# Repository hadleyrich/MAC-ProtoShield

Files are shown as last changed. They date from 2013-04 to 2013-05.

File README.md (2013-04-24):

MAC ProtoShield
===============
Copyright 2013 nice technology Ltd  
Website: <http://nicegear.co/mac-protoshield>

Based on the Freetronics ProtoShieldShort
<http://www.freetronics.com/pss>

A specially shaped prototyping shield for the Arduino, designed to be
able to clear the RJ45 jack and a PoE Module on an Ethernet Shield
or Freetronics EtherTen. Includes space for a MAC address chip.

Features:

 * Designed to fit a Freetronics EtherTen with an 802.3af PoE module
   installed, or a standard Ethernet Shield.
 * Arduino "R3" header layout.
 * Surface mount pads for an I2C connected EEPROM with built in MAC
   address (MicroChip 24AA02E48).
 * Pads for reset button connected to Arduino reset pin.
 * Parts overlay on both the top and the bottom so you can see what you
   are connecting without having to keep turning the board over.

LICENSE
-------
Licensed under the TAPR Open Hardware License (www.tapr.org/OHL).
See the "LICENSE" file within this repository for the full license
in plain text format.

INSTALLATION
------------
The design is saved as an EAGLE project. EAGLE PCB design software is
available from www.cadsoftusa.com free for non-commercial use. To use
this project download it and place the directory containing these files
into the "eagle" directory on your computer. Then open EAGLE and
navigate to Projects -> eagle -> MAC-ProtoShield.

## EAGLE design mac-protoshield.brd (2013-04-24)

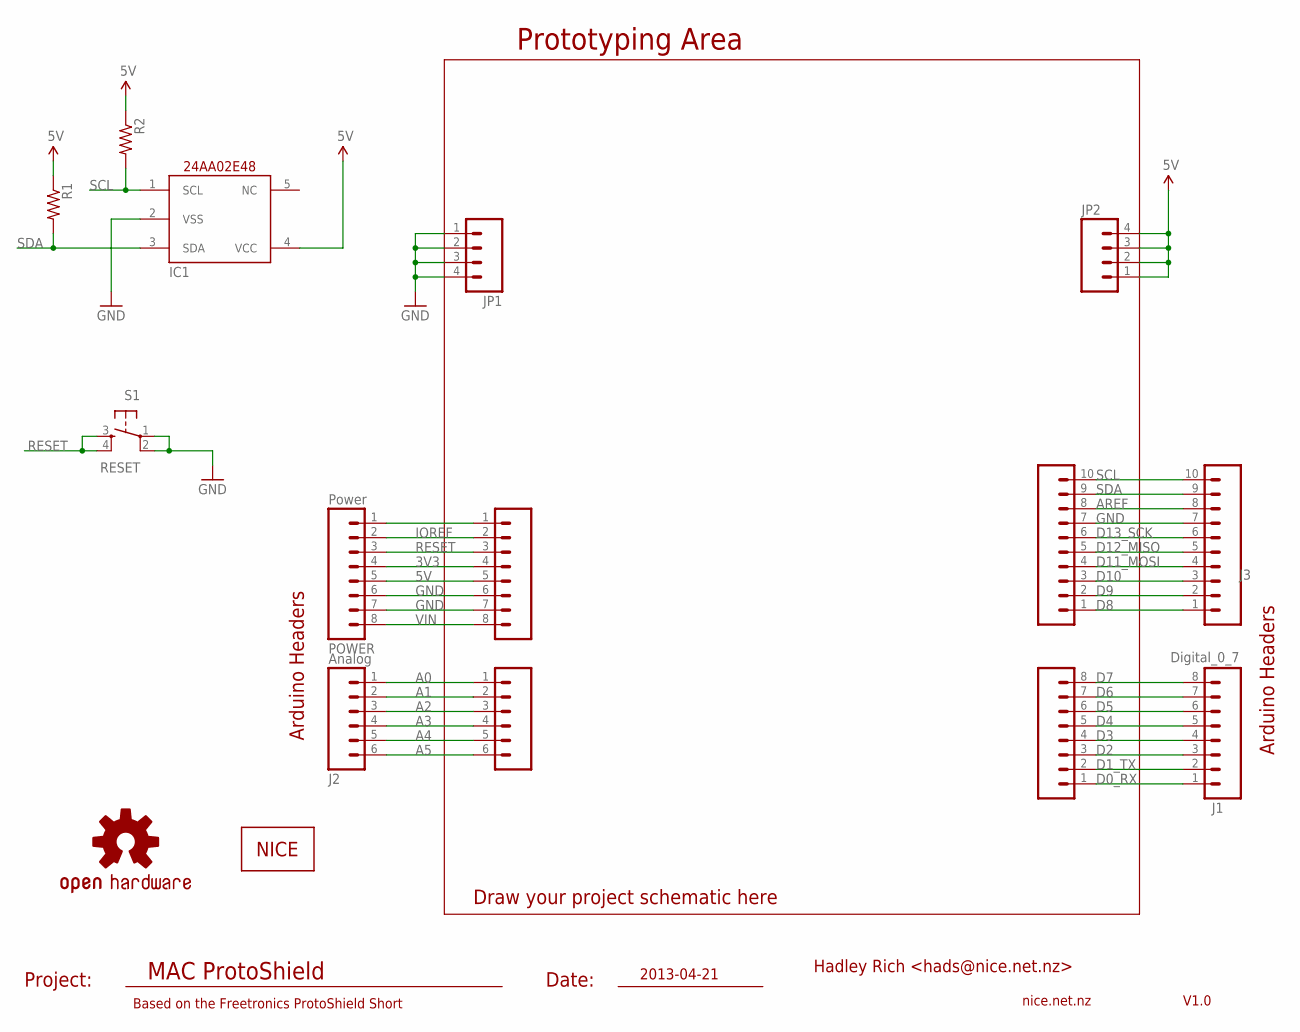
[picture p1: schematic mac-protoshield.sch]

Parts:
IC1: 24AA-2E48; SOT23-5
J1: Digital_0_7; 1X08
J2: Analog; 1X06
J3: Digital_8_13; 1X10
JP1, JP2: M04PTH; 1X04
LOGO1: OSHW-LOGOS; OSHW-LOGO-S
POWER: Power; 1X08
R1, R2: RESISTOR0805-RES; 0805
S1: RESET; TACTILE-PTH
SL1: Digital_0_7; 1X08
SL2: Analog; 1X06
SL3: Digital_8_13; 1X10
SLP: Power; 1X08
U$5: NICE-LOGO04; NICE-LOGO-04

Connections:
3V3: POWER.4, SLP.4
5V: IC1.4 (VCC), JP2.1, JP2.2, JP2.3, JP2.4, POWER.5, R1.1, R2.1, SLP.5
A0: J2.1, SL2.1
A1: J2.2, SL2.2
A2: J2.3, SL2.3
A3: J2.4, SL2.4
A4: J2.5, SL2.5
A5: J2.6, SL2.6
AREF: J3.8, SL3.8
D0_RX: J1.1, SL1.1
D1_TX: J1.2, SL1.2
D2: J1.3, SL1.3
D3: J1.4, SL1.4
D4: J1.5, SL1.5
D5: J1.6, SL1.6
D6: J1.7, SL1.7
D7: J1.8, SL1.8
D8: J3.1, SL3.1
D9: J3.2, SL3.2
D10: J3.3, SL3.3
D11_MOSI: J3.4, SL3.4
D12_MISO: J3.5, SL3.5
D13_SCK: J3.6, SL3.6
GND: IC1.2 (VSS), J3.7, JP1.1, JP1.2, JP1.3, JP1.4, POWER.6, POWER.7, S1.1, S1.2, SL3.7, SLP.6, SLP.7
IOREF: POWER.2, SLP.2
unnamed: POWER.1, SLP.1
RESET: POWER.3, S1.3, S1.4, SLP.3
SCL: IC1.1 (SCL), J3.10, R2.2, SL3.10
SDA: IC1.3 (SDA), J3.9, R1.2, SL3.9
VIN: POWER.8, SLP.8

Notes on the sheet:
MAC ProtoShield
V1.0
nice.net.nz
Prototyping Area
Arduino Headers
Project:
Date:
Draw your project schematic here
Based on the Freetronics ProtoShield Short
2013-04-21
Hadley Rich <hads@nice.net.nz>

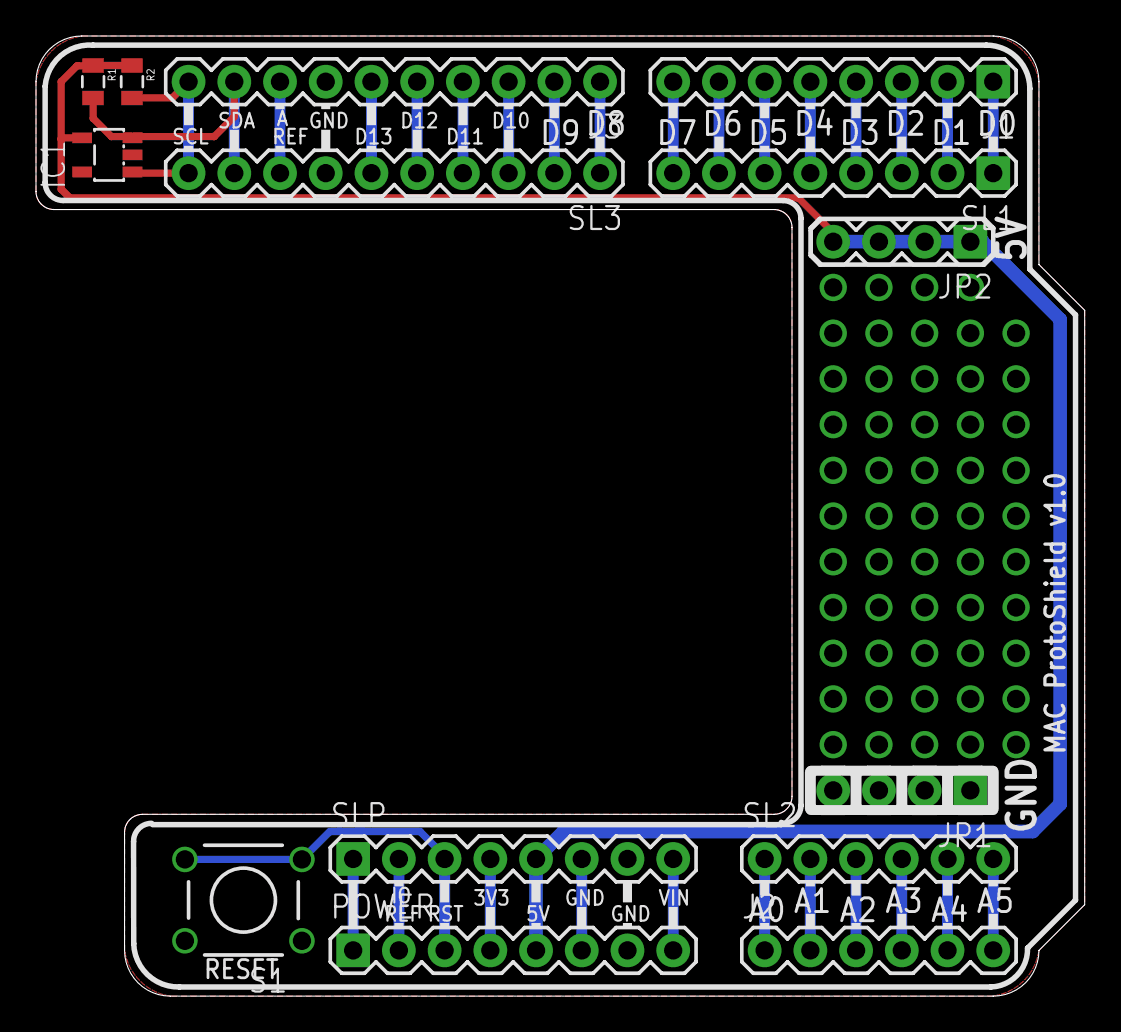
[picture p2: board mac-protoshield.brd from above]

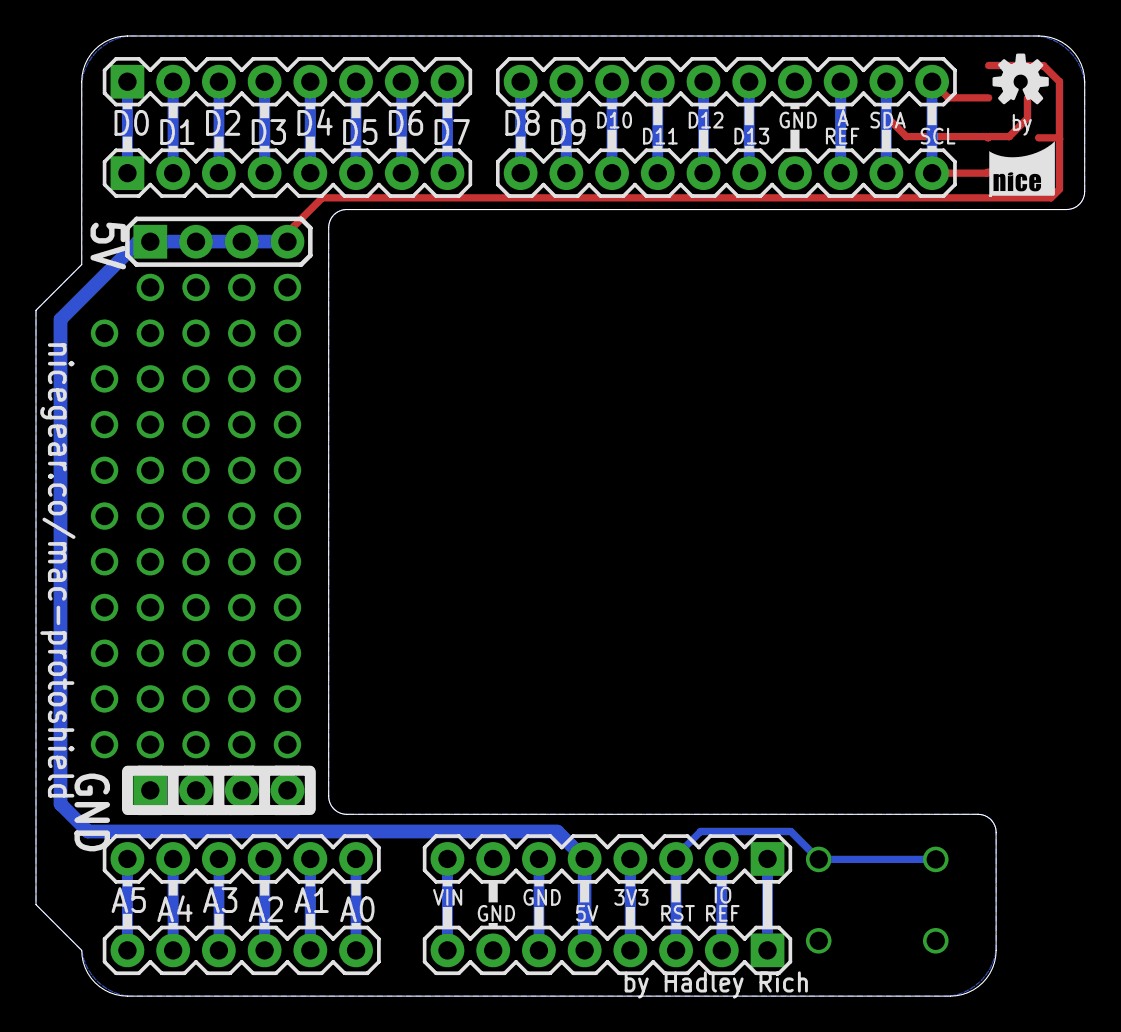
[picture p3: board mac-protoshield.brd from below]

Board: 2 copper layers, 58.3 x 53.3 mm, 16 parts (2 on the bottom side), 30 nets.

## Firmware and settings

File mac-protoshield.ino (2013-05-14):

#include <Wire.h> // Required for I2C communication

#define I2C_ADDRESS 0x50 // Address of the EEPROM

byte mac[] = { 0x00, 0x00, 0x00, 0x00, 0x00, 0x00 }; // This will be replaced
char macstr[18]; // Just used to print the MAC address to serial

void setup() {
  Serial.begin(9600); // Start serial communication
  Wire.begin(); // Start I2C communication

  // Read the separate MAC address parts from the EEPROM
  mac[0] = read_register(0xFA);
  mac[1] = read_register(0xFB);
  mac[2] = read_register(0xFC);
  mac[3] = read_register(0xFD);
  mac[4] = read_register(0xFE);
  mac[5] = read_register(0xFF);

  // Format the mac address into a string for printing
  snprintf(macstr, 18, "%02x:%02x:%02x:%02x:%02x:%02x",
    mac[0], mac[1], mac[2], mac[3], mac[4], mac[5]);

  // Print the address to the serial port
  Serial.print("MAC: ");
  Serial.println(macstr);
}

void loop() {
}

byte read_register(byte r) {
  /*
    Read a register address from an I2C slave
  */
  Wire.beginTransmission(I2C_ADDRESS); // Begin talking to EEPROM
  Wire.write(r); // The address of the register we want
  Wire.endTransmission(); // Send the data
  Wire.requestFrom(I2C_ADDRESS, 1); // Request one byte from the EEPROM
  while (!Wire.available()); // Wait for the response
  return Wire.read(); // Return the value
}

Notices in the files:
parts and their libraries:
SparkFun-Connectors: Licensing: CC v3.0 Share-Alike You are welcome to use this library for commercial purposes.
